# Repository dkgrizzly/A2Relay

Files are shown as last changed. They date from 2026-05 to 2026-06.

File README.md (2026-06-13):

> [!WARNING]
> This design is currently untested as of 5/26/2026. There may be errors in the design or example code.
> 
> Update 6/12/2026: Because the 74_259 resets to all outputs low and the relay module is active low, all the relays default to being on at startup.
> Adding a 74_240 inline between the 74_259 and relay board will correct for this in a future revision.
> 
> Schematics and Gerbers for an "OOPS! Inverter" board will be uploaded soon.

> [!CAUTION]
> It is advisable to remove the VCC jumper on the relay board and power the relays with the GND and JD-VCC pin.
> The game port is designed to provide a maximum of 100ma, and with all relays turned on more than 500ma load will be present.

# Apple II Gameport Relay Interface

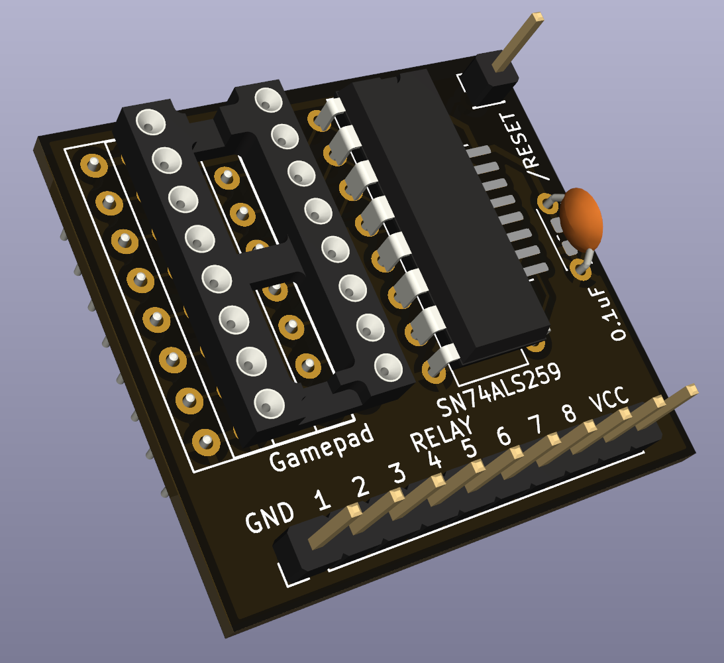
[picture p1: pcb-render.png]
PCB Rendering


This is a design for a small PCB to control inexpensive [8-relay modules](https://amzn.to/4dw5lLv) <sup>(Amazon affiliate link)</sup> using the Apple II's gameport annunciators and strobe output.
Use AN3 to set on/off state, AN0-AN2 to select which relay to control, and $C040 strobe to store the value.
All pins are passed through to a socket where you can attach a gamepad, paddles, or other input device.

# Applesoft BASIC Example
```
10 REM To turn on the first relay:
20 PEEK -16295 : REM Clear AN0 $C059
30 PEEK -16293 : REM Clear AN1 $C05B
40 PEEK -16291 : REM Clear AN2 $C05D
50 PEEK -16290 : REM  Set  AN3 $C05E
60 PEEK -16320 : REM Strobe    $C040
```

# 6502 ASM Example
```
0300  lda $C059 ; Clear AN0
0303  lda $C05B ; Clear AN1
0306  lda $C05D ; Clear AN2
0309  lda $C05E ;  Set  AN3
030c  lda $C040 ; Strobe
030f  rts
```

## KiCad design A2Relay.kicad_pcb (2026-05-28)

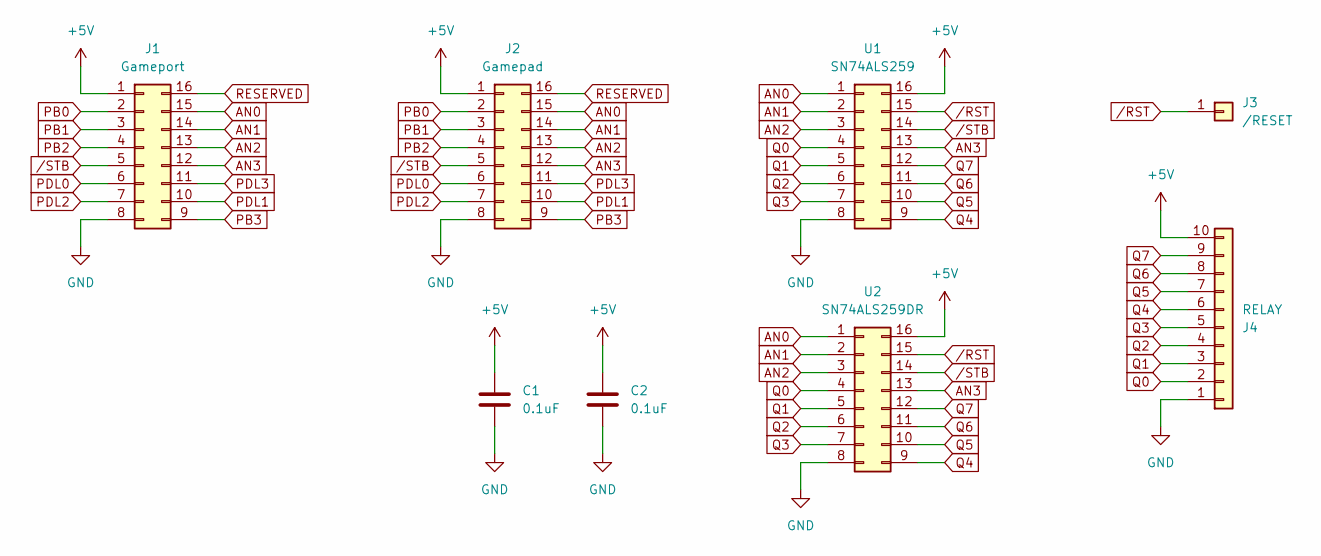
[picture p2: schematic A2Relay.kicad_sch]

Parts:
C1: 0.1uF; C_Disc_D4.3mm_W1.9mm_P5.00mm
C2: 0.1uF; C_0603_1608Metric_Pad1.08x0.95mm_HandSolder
J1: Gameport; DIP-16_W7.62mm_Socket
J2: Gamepad; DIP-16_W7.62mm
J3: /RESET; PinHeader_1x01_P2.54mm_Vertical
J4: RELAY; PinHeader_1x10_P2.54mm_Vertical
U1: SN74ALS259; DIP-16_W7.62mm
U2: SN74ALS259DR; SOIC-16_3.9x9.9mm_P1.27mm

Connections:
+5V: C1.1, C2.1, J1.1, J2.1, J4.10, U1.16, U2.16
AN0: J1.15, J2.15, U1.1, U2.1
AN1: J1.14, J2.14, U1.2, U2.2
AN2: J1.13, J2.13, U1.3, U2.3
AN3: J1.12, J2.12, U1.13, U2.13
GND: C1.2, C2.2, J1.8, J2.8, J4.1, U1.8, U2.8
PB0: J1.2, J2.2
PB1: J1.3, J2.3
PB2: J1.4, J2.4
PB3: J1.9, J2.9
PDL0: J1.6, J2.6
PDL1: J1.10, J2.10
PDL2: J1.7, J2.7
PDL3: J1.11, J2.11
Q0: J4.2, U1.4, U2.4
Q1: J4.3, U1.5, U2.5
Q2: J4.4, U1.6, U2.6
Q3: J4.5, U1.7, U2.7
Q4: J4.6, U1.9, U2.9
Q5: J4.7, U1.10, U2.10
Q6: J4.8, U1.11, U2.11
Q7: J4.9, U1.12, U2.12
RESERVED: J1.16, J2.16
/RST: J3.1, U1.15, U2.15
/STB: J1.5, J2.5, U1.14, U2.14

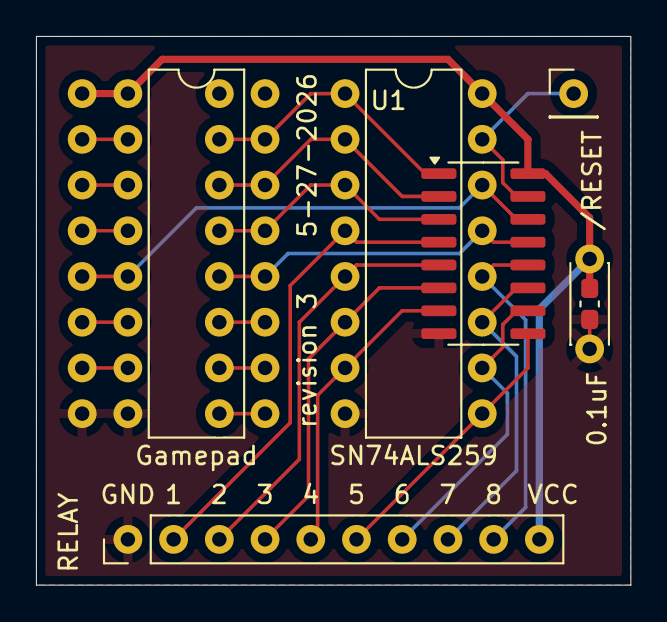
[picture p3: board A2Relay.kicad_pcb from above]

Board: 2 copper layers, 33.0 x 30.5 mm, 8 parts (0 on the bottom side), 25 nets.

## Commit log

2026-05-26 Update README with description, warnings and examples
    Add description, warnings and usage examples for relay interface
2026-05-26 Add PCB Render
2026-05-26 Update to KiCad 9.0, add surface mount capacitor, swap VCC / GND on relay connector
    [A2Relay-B_Cu.gbr, A2Relay-B_Mask.gbr, A2Relay-B_Paste.gbr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]
2026-05-26 Updated PCB Render
2026-05-27 Removed old drill files
    [A2Relay-NPTH.drl, A2Relay-PTH.drl]
2026-05-28 revision 3 - initial prototype run
    [A2Relay-B_Cu.gbr, A2Relay-B_Mask.gbr, A2Relay-B_Paste.gbr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]
2026-06-13 Note about output inversion
    Updated warning about outputs being inverted from what the relay board wants.

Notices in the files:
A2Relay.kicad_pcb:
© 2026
